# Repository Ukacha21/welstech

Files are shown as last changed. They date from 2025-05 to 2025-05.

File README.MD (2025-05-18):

# **WELSTECH**
#### *WEARABLE LIFE SAVER TECHNOLOGY*

#### Description:
**Welstech** is a wearable prototype in a type of wrist band that aims to deliver help to people with special needs. By constantly monitoring health conditions and their current status, the wearable prototype is able to tell wether the user is in situation that needs special care and immediate attention. Later on gives alerts the people nearby through a buzzer, with beeping intervals depending on how severe the condition is.

#### Components:
I will use `esp32-s3 mini/tiny` or `esp32-s3 zero` as the main microcontroller for this project. Here are all the components I'm gping to use in the project:
    
- **ESP32-S3 Zero**: Our main microcontroller.
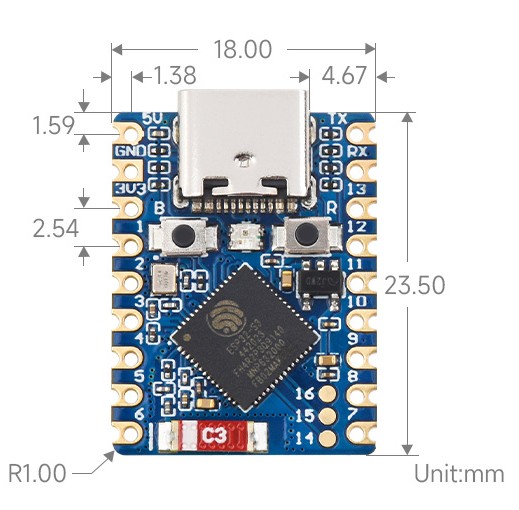
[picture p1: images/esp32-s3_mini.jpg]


- **Buzzer**: if we find a smaller one that can fit into the prototype.
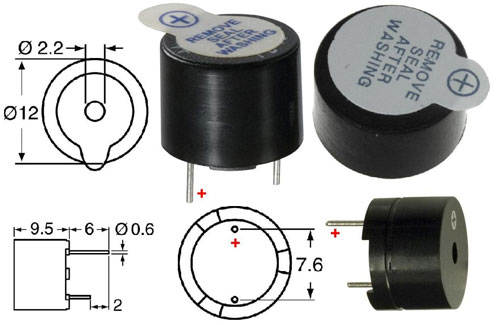
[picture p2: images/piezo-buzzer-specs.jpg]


- [`Removed`] **PushButton(Silent if possible)**: To be used as an action-button.
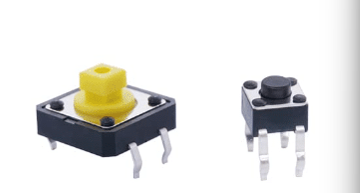
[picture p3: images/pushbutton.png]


- [`Removed/Still implementable`] **Switch**: To be used as feed or power interrupt between DCVin voltage supply and ground when necessary.
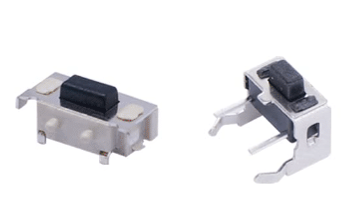
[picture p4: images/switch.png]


- [`Removed`] **Resistors**: a series of 10k resistors for pulldown and 330-OHM for LEDs(if necessary).
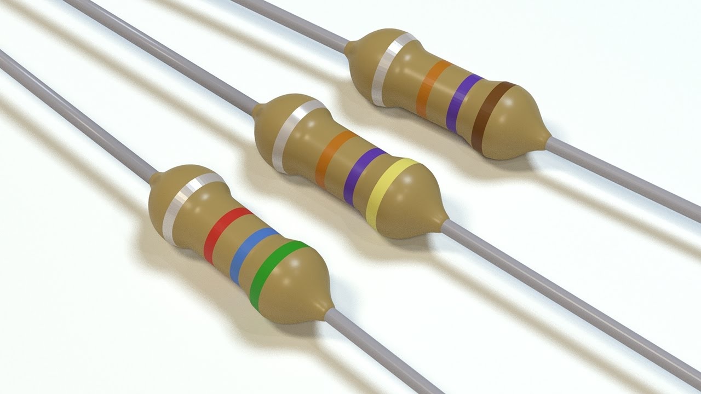
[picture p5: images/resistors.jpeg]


- [`Removed/Still implementable`]**Battery**: 3 pieces of 1.5 mini batteries connected in series,to output and average of 4.5V. Or 4 pieces and a silicon diode to drop voltage near 5.xV.
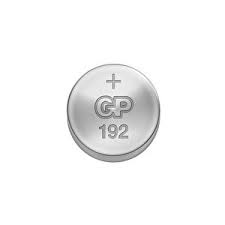
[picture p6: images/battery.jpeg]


- **Heart Pulse Monitor Sensor**: The sensor that will sense peak values and return data about the pulse of the user.
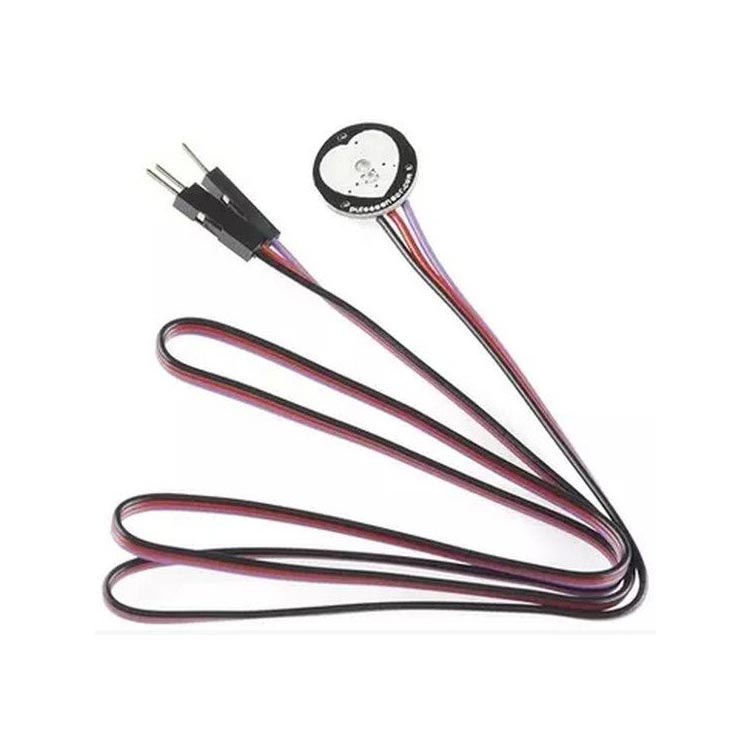
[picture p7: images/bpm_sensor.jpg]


- [`Removed`] **0.96" OLED Display**: To display data when necessary.
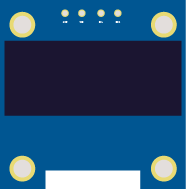
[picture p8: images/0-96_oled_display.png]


- **Jumper Wires**: To be used during Demo, before product release.
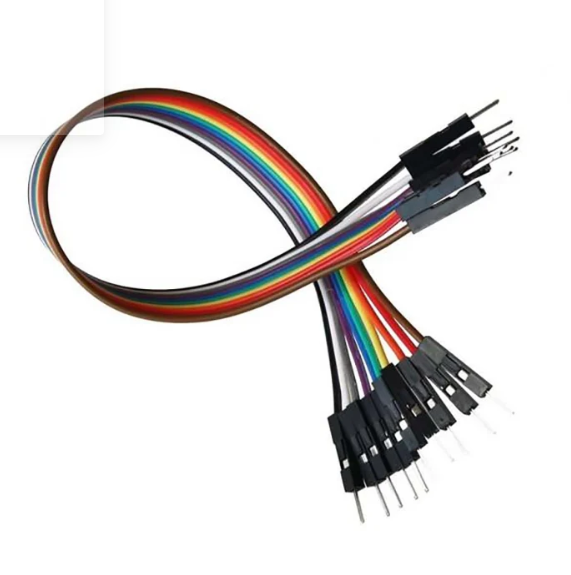
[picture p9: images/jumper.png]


- [`Removed`] **Perforated Board Soldering PLate**: The main circuit plane, to be soldered onto the base.
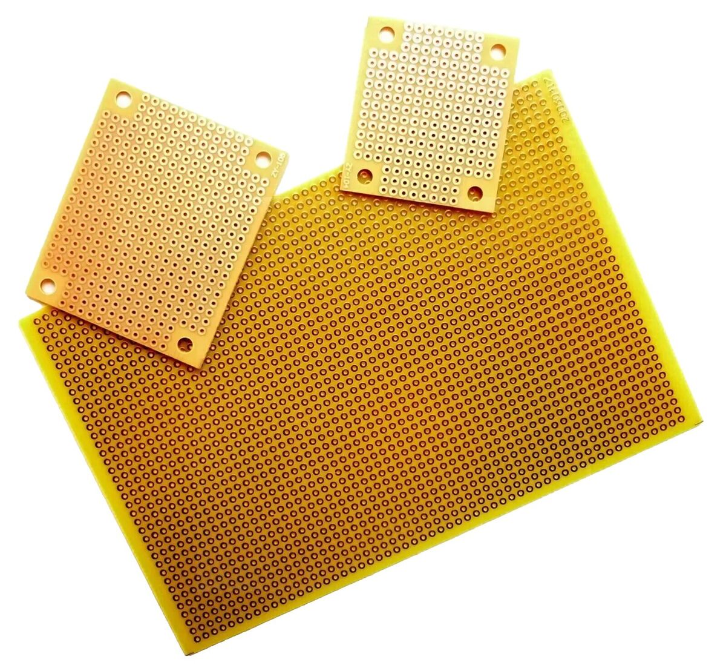
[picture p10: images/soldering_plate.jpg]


- **Thin Wires**: Thin circuit wires to be soldered onto the Welding plate and used ın other components.
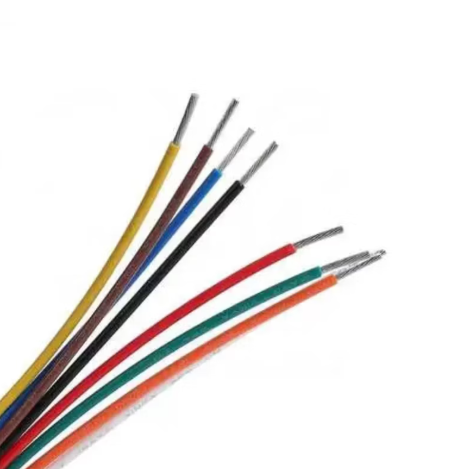
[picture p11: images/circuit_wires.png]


#### Algorithm:
As soon as the device is powered on with the code flashed and successfully uploaded, it shall start fetching the data from the heartrate pulse sensor, do the required normalization, calculate the average BPM and display it to the user in a human readable format. Here, after removıng the OLED Display, we are going to show the data through http protocol and continuous WiFi data streaming[locally].

If the BPM read is below a certain threshold--to be different for each user(eg. football player vs a teacher)--the buzzer will give a warning, short beeps-- or the mobile will notify the user and anybody else chosen among SOS contacts. In this mode, the action button will function as a silencer or mute button, to indicate that everything is okay. If the button is not pressed to mute the buzzer within a certain time, the buzzer play intervall will gradually increase, untill someone--rescue team or emergency service--presses it. The rescue team will be able to read from the display as well to facilitate their work in telling the user's(or patient's) current status and probably predict the reason of passing out.

#### Why **WELSTECH**?------start from here later on
Taking people with special needs into consideration and as a our main targeted audience, welstech aims to minimize the need of continuous human supervision, and decrease it to as much as possible. As previously said, if a button is not pressed within a certain amount of time, it does not necessarily mean that the user is unconcious, rather a starting point to tell the environment around it that urgent attention is needed.

#### [`OLD Schematic`] Schematics:

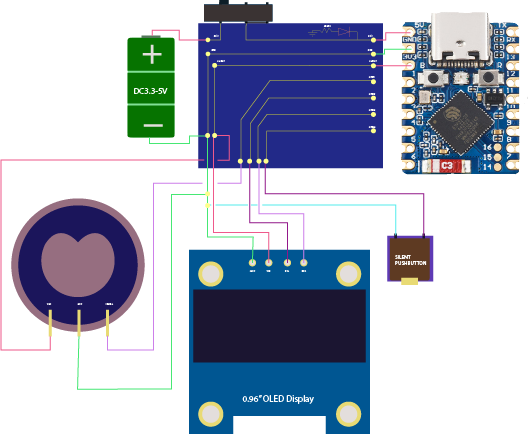
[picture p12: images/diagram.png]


----

#### [`NEW Schematic`] Schematics:

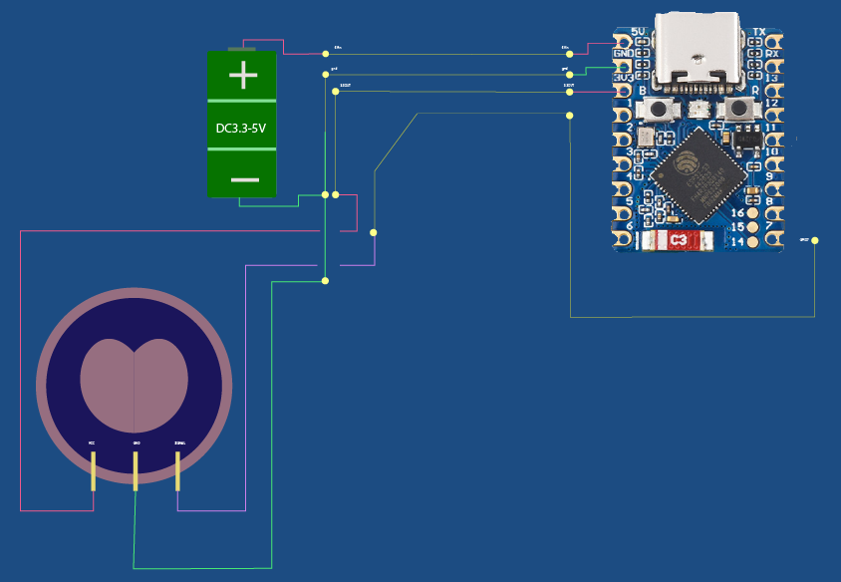
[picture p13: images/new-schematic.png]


#### What can be improved?

* find a smaller buzzer to use as environmental warning method.

* [`Done-with integrated BLE-WiFi`] use a bluetooth and/or wifi module to enable communication peripherals between the esp32 and a the phone.

* if we manage to find a smaller bluetooth or wifi modules, as tiny as possible we could no longer need esp32 and use microhips, such as pic16f84x, pic16f877x or stm32 chips. Thus minimizing significantly the size of the main base prototype.

## Mobile App:

Welstech Mobile is the name of the mobile app, currently almost finished, done with flutter and dart for elegancy and minimalism.

Mobile app is ready, just waiting to succedd connectiing to bluetooth with  the name specified on th code[**`ESP32_BT`**], to see if it works.

---

## Updates:
* `WiFi or Bluetooth`: 

**Wifi**: We started with Wifi.h, the plan was to use wifi for faster information and data transfer. The biggest drawback was oled's sensitivity ti heat, it could stop working as expected after a while, it was affected for being too close the esp32 main board.  And the challenge here it manage the esp32's heat dissipassion which did not turn out as easy as it looked.

**Bluetooth**: The alternative solution for this seemed to be switching to bluetooth. It's important to keep in mind that some esp board do not support `bluetooth classic` as it is in our case--ESP32S3-Zero, being Bluetooth Low Energy BLE. The most recommended BLE libraries are 

* NimBLE - Optimized for Wearables and compact devices -- third party lib.
* BLEServer - Built in llibrary that comes with espressif lib managger.

We tried NimBLE, we could upload the test code to the board successfuly, but it wouldn't broadcast, and thus, we could  find the board in the nearby BLE devices, after sca.

So we swiched to BLEServer, we uploaded the test code successfully for BLEServer to our esp board, it does appear in the scanned nearby devices list, but somehow we're failing to connect.  I tried with `Redmi 12 Pro`, `Redmi 7 Pro` and `Samsung tab S7 FE`. The Xiaomis appear to try to connect, even tho unsuccessful, it appears in the list of paired devices. Samsung on the other hand, seems to be the most too the point, telling us exacly that it failed to connect.

### Solution?

For now, the solution seems to be removing the display, and relying entirely on web based platforms to access the data, read and visualize.

Current plan is to completely redesign  the prototype and circuit element, remove the screen, buzzer had already been removed, still thinking about the action button. And keep the main board, sensor, and the prototype's cover, the case itself. 

Step 2: Switch back to wifi, use telegram bot for communication, and see if we can integrate the bot's retrieved information into our welstech mobile flutter app. Remodel the prptptype's case to put some ventilation pathways to relief the heat amd help with heat dissipation.

## Updates:
We are currently using ESP's wifi on access point mode, initialized hotspot from the esp board, coonnected to it from the browser, and typically we should be able to access any stremmed data from the browser using "192.168.4.1". And it worked.

#### Sample test on http protocol:

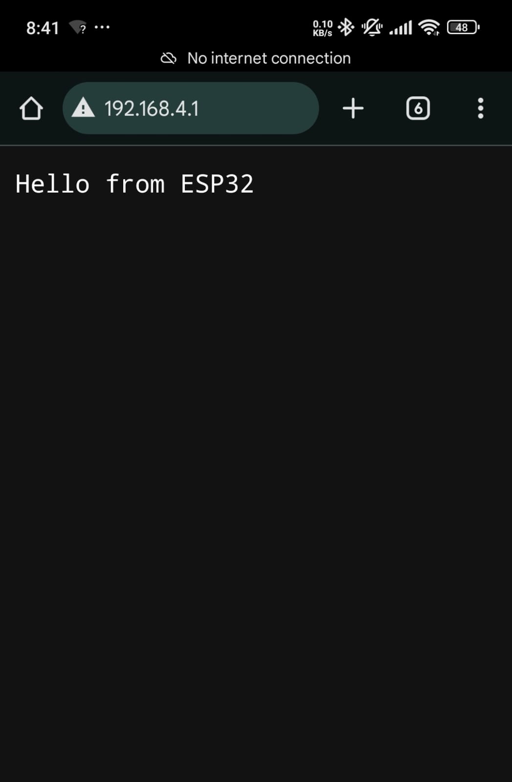
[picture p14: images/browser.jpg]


Now tring to access it using socket from the flutter side, raised multiple errors. Soo instead or raw socket and/or tcp we just used http client and updated the dependecies in our pubspec.yaml.

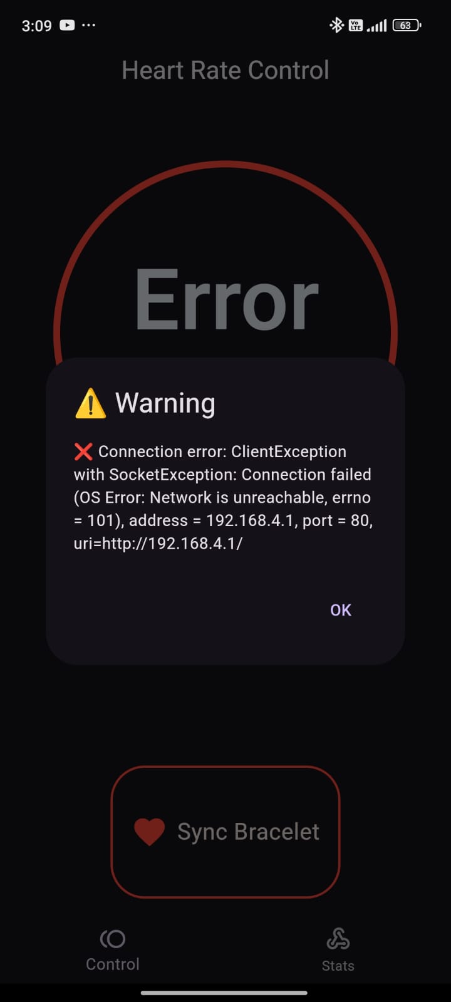
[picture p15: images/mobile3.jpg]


After some  reseaches i came to know that emulators do not allow raw http data for security reasons, so after each minor change, i would have to rebuild the apk file and try on a real mobile device. Now lets do that, best of luck.

#### Sample test on http protocol:

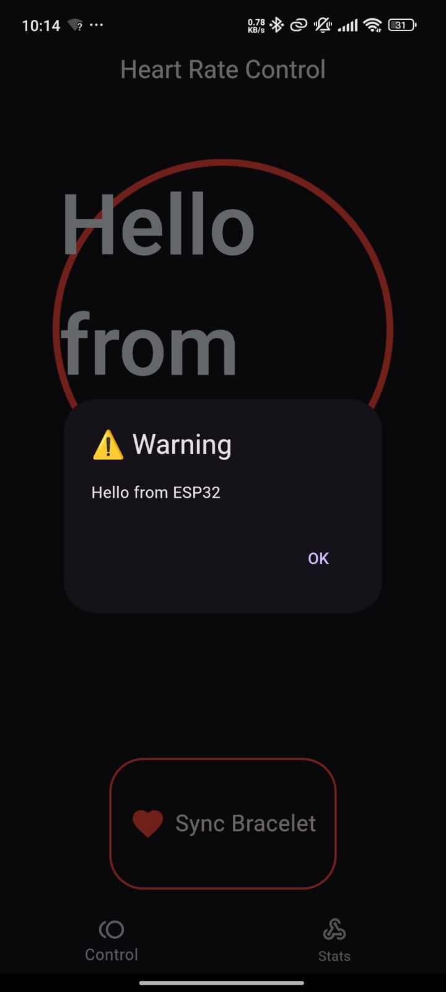
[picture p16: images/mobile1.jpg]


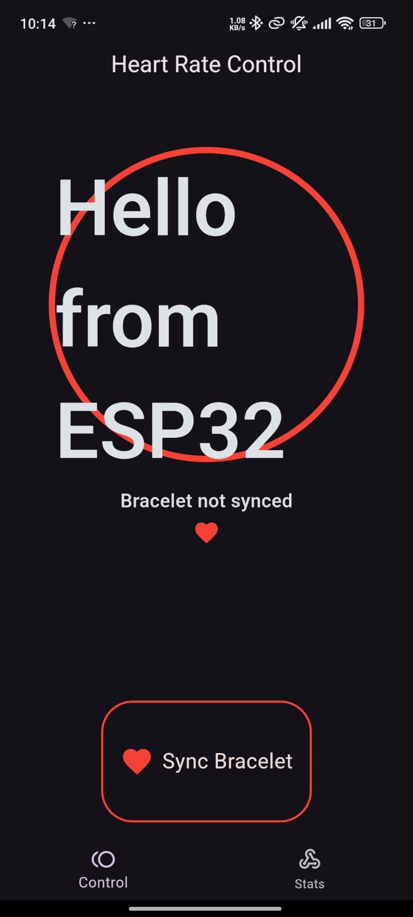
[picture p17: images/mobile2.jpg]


And another thing, if we managed to get the data from the browser, we can now be sure to remove the screen, and now we can 3D print the smaller prototype with small holes to be used as vents.

Now we successfully got the data on the mobile app, for now we just tried to show the analog value that the sensor returns as raw data, using readAnalog(). We did not calculate any BPM up until here:

#### Data on flutter  app:

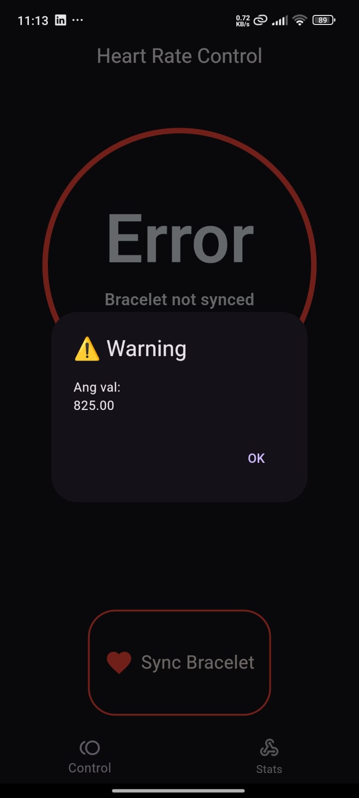
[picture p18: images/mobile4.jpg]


## Updates: 

Project is successfull, now we can print the 3D prototype and improve the mobile side, to read the values every 10 seconds and return the estimate bpm.

One more thing, we still havent gotten the optimum threshold, this can only be done either by changing small values every time, or watching the peak changes closely from the mobile phone, http in the browser cannot update itself every second, that is something to be imlpemented in the mobile. to make requestas every half a second or 200 ms, to detect the optimum threshhold, and calculate bpm accordingly.

## Updates: 

A mistake made by me, caused the deliver of the prototype to take longer than expected. 

Printed the 3D base, but came out larger than thought of. And the reason for that is, I had measured the diameter as 43mm, but when modeling the surpafecs on solidworks, I mistakenly put 43 as the radius, and it turned out larger than expected.

#### Faulty Prototype:

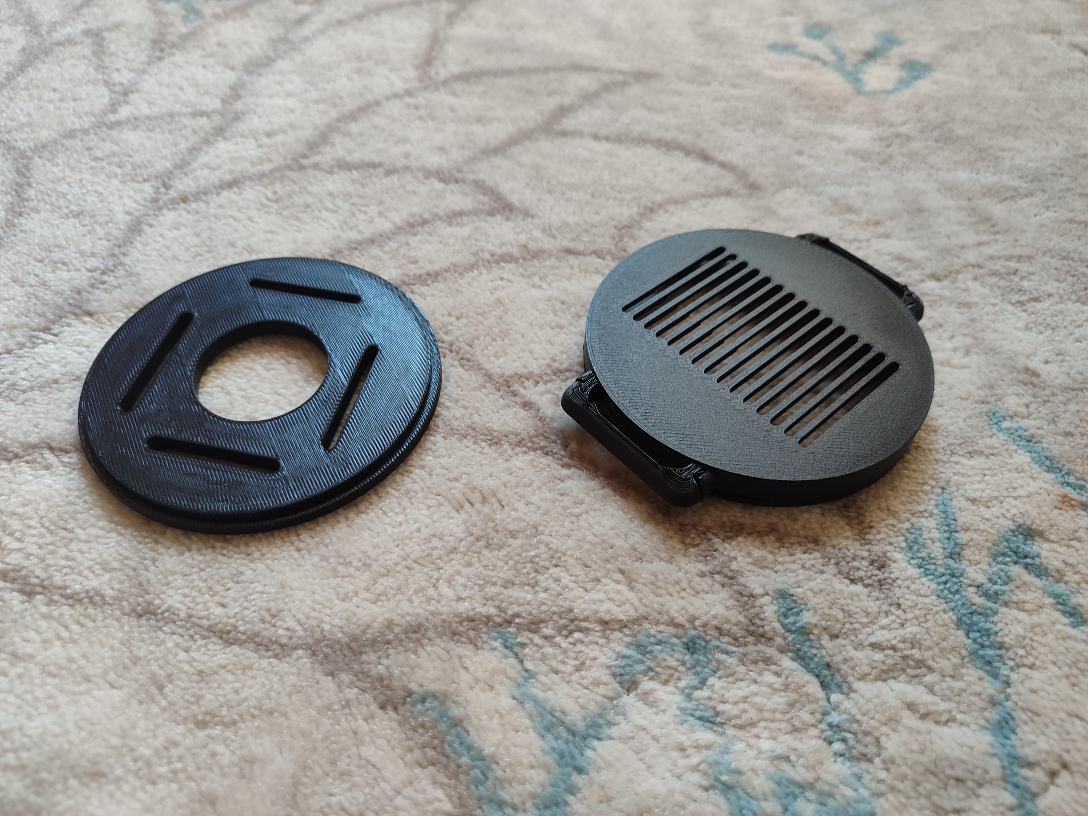
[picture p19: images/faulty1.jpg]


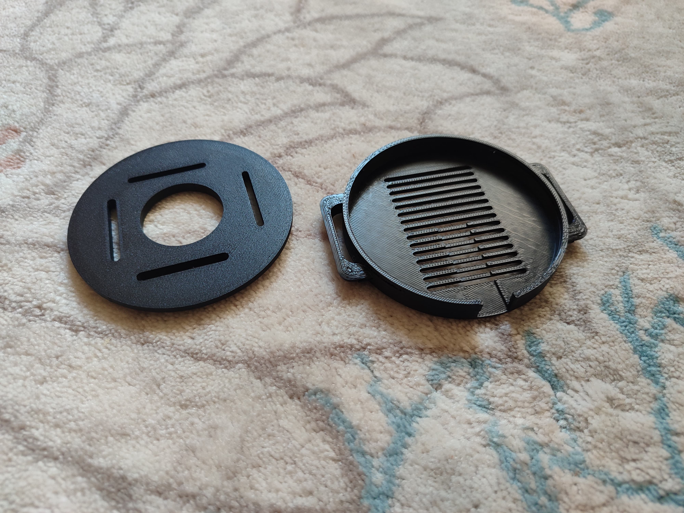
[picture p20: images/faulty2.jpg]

#### Comparing the sizes to a real watch:

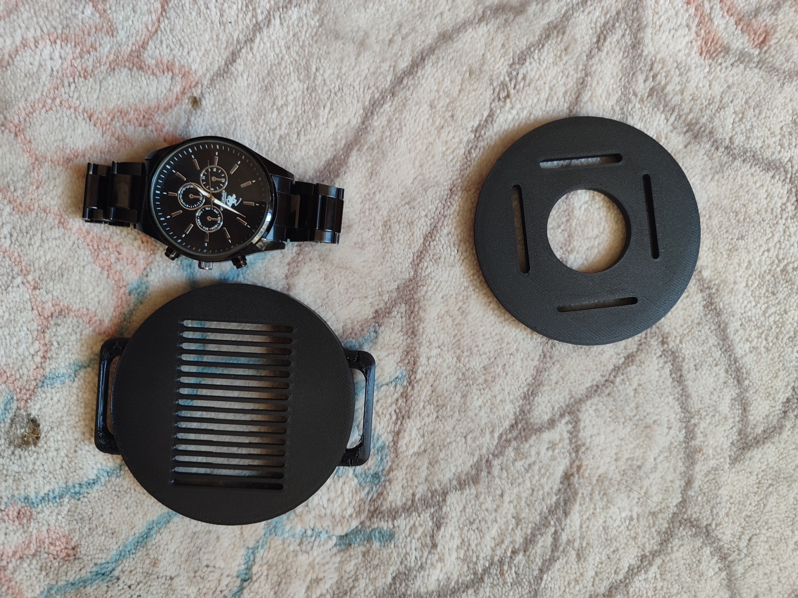
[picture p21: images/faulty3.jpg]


While redesiging on Solidworks, we're basicaly just going to set the new sizes as half of the previous ones. e.g: 'instead of 43, use 43/2'. Taking its rescpective tolerances into consideration of coursse.

## Updates: 

After printing our latest protype and placing the microcontroller and sensor inside, it worked just fine. 

The  optimum threshold is 852, and the Average output BPM rate was a value in the  interval of 96-100.

## Results: 

Current prototype and finished design:

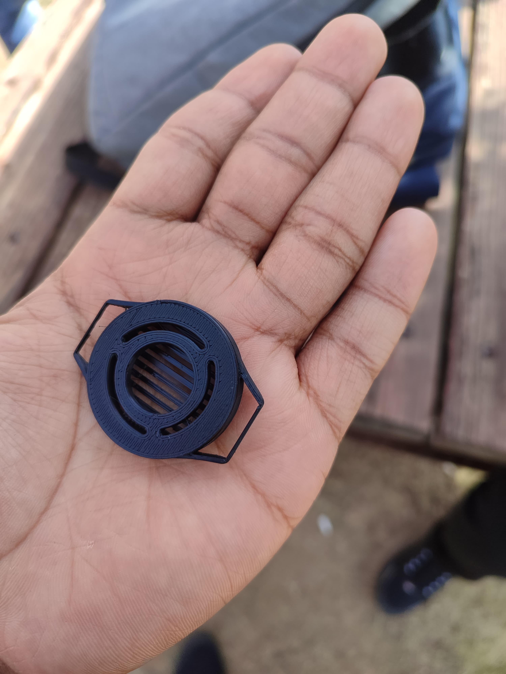
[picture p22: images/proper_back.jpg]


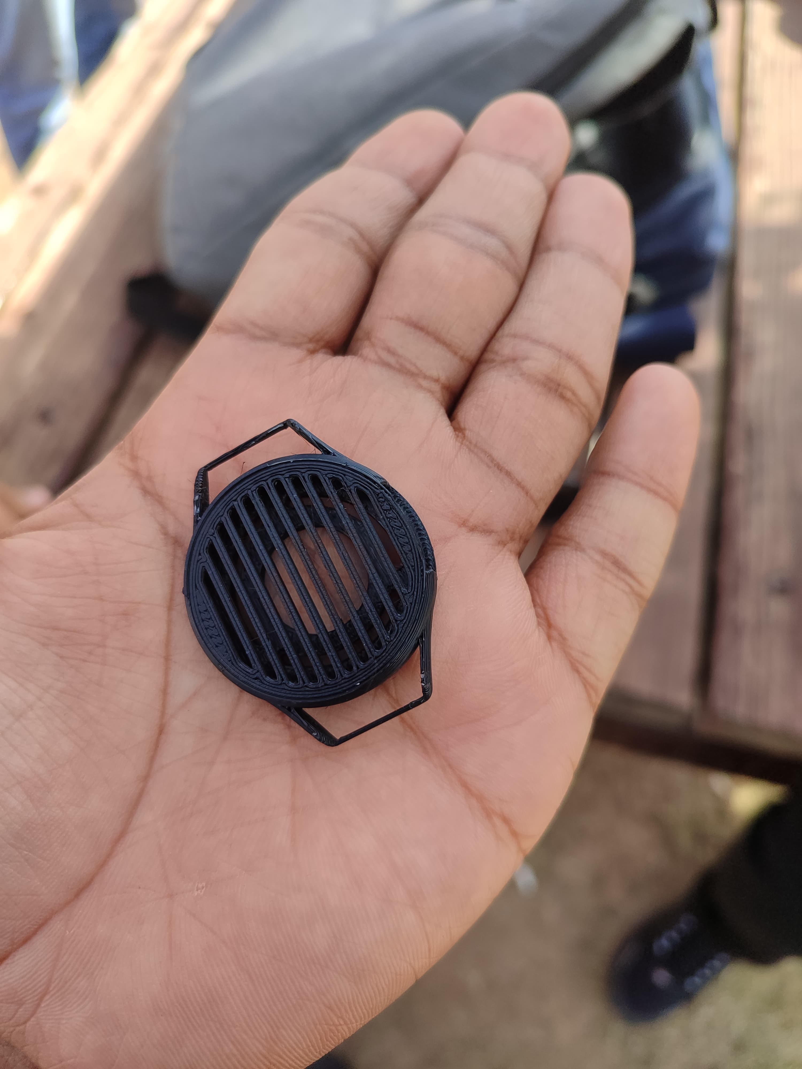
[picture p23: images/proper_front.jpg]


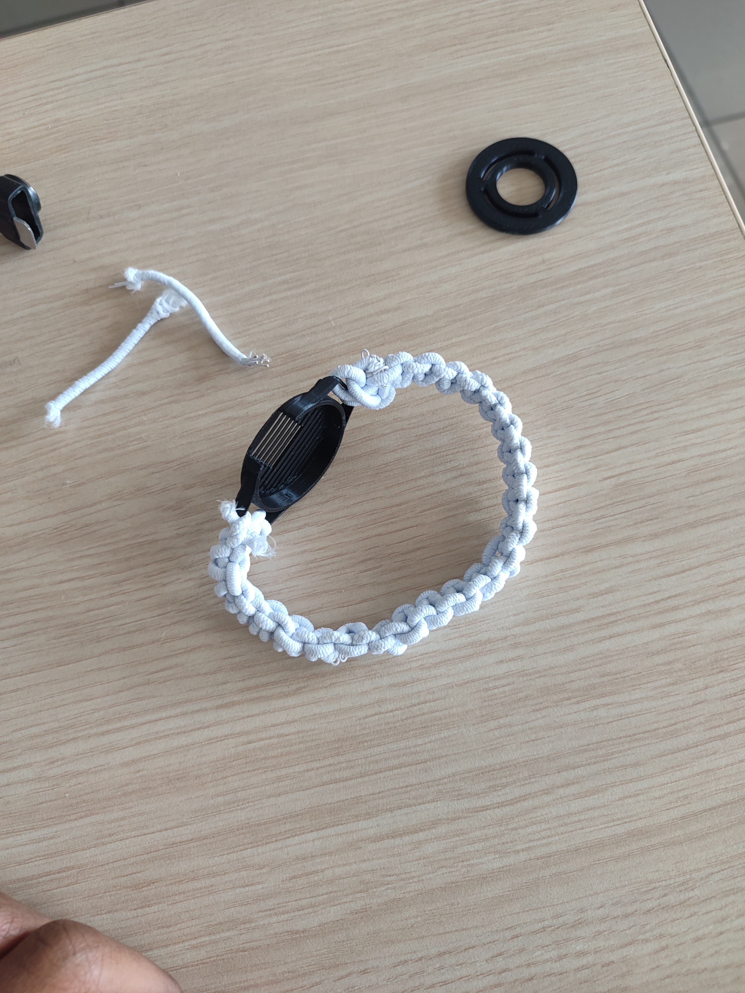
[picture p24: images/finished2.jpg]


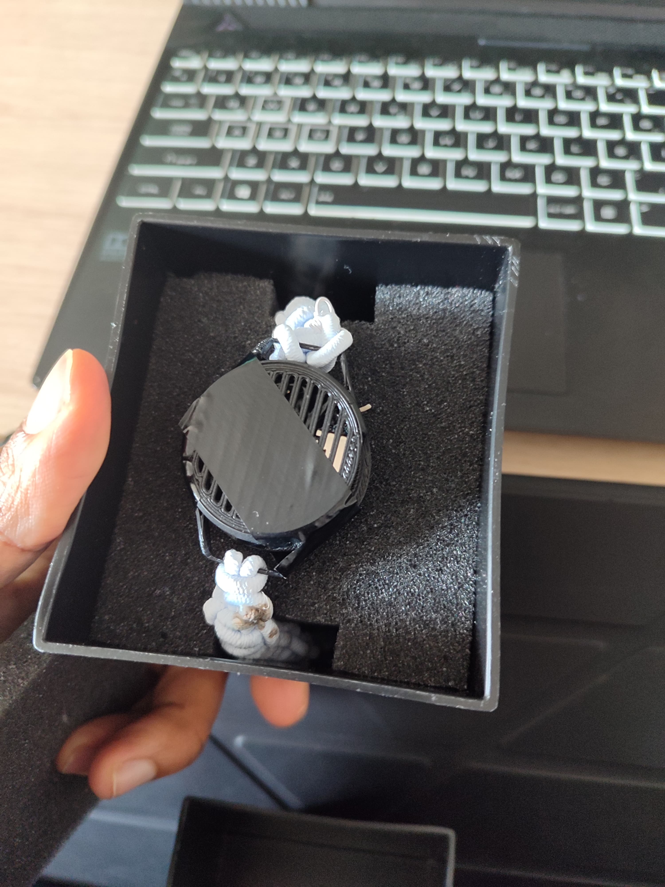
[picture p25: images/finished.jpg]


---------

The fisrt thing shown when app in not in sync with bracelet, the background borderline colors turn red. 

After sync it turns blue

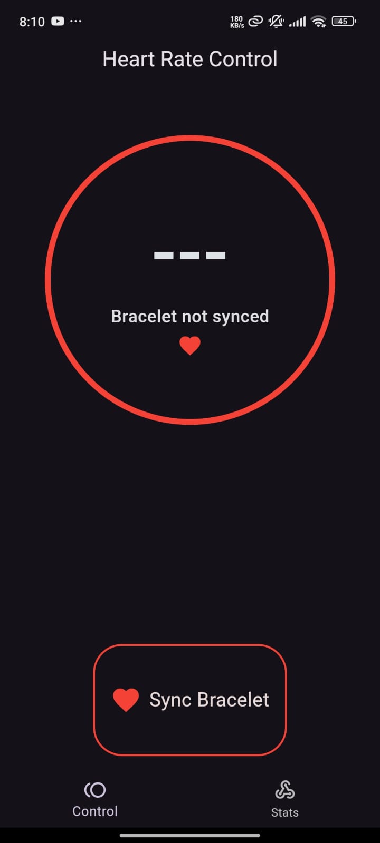
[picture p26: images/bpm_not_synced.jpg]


And here the average BPM results:

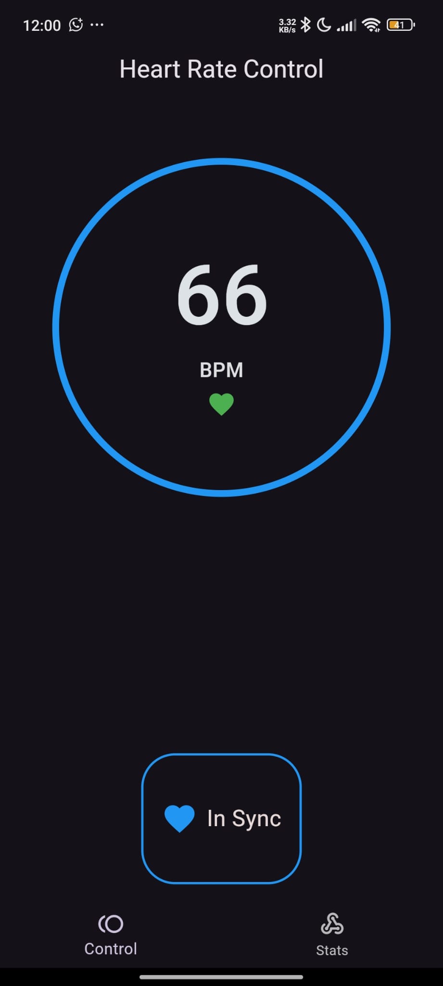
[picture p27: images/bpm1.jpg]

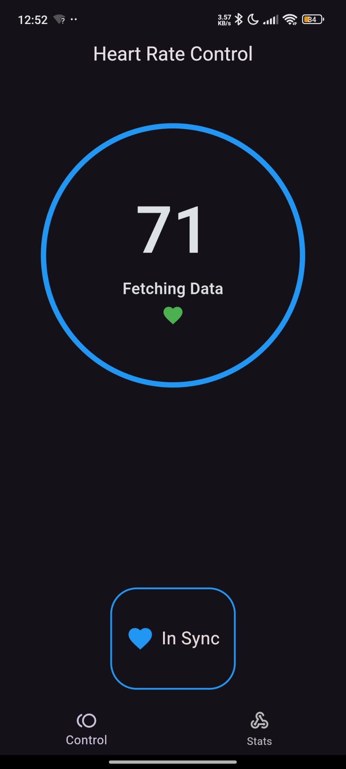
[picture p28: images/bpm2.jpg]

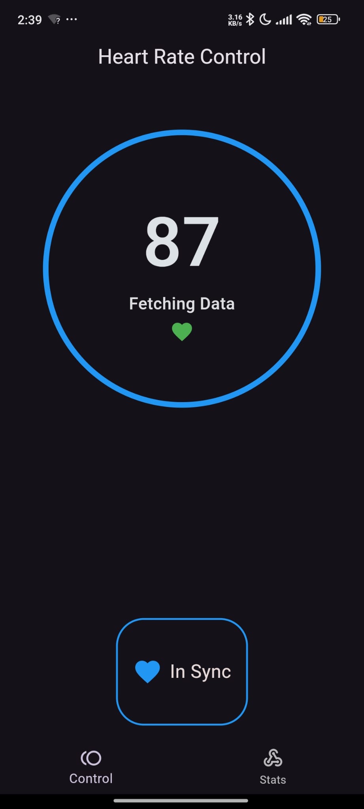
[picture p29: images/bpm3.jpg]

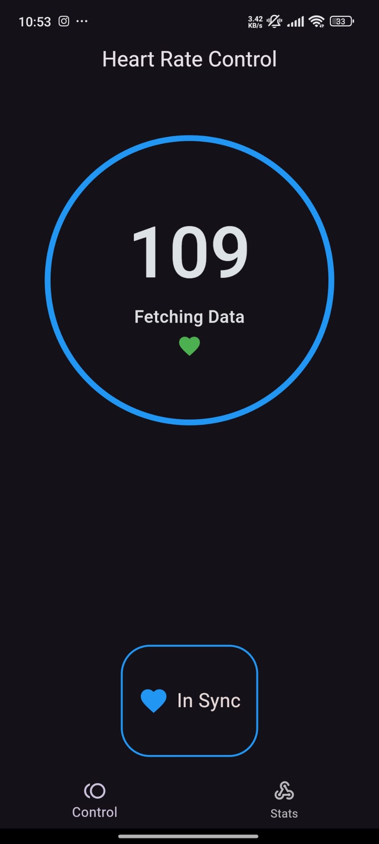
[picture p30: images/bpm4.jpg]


Detailed Video on Youtube:

[welstech video](https://youtu.be/DE1oGRj5kBM?si=-mU4gTcb0TAKlGFt)

## What can be added or improved?

 * GPS Location
 * Instead of WiFi, use BLE--Bluetooth Low Energy--to significantly prevent board overheat
 * Send SMS, Telegram or Whatsapp text to contact--GSM may be needed
 * Add a physical action button
 * If possible use a smaller batttery(rechargeable and batter charging and feed circuit integrated)
 
 * ...

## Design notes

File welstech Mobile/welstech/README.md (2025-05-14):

# welstech

A new Flutter project.

## Getting Started

This project is a starting point for a Flutter application.

A few resources to get you started if this is your first Flutter project:

- [Lab: Write your first Flutter app](https://docs.flutter.dev/get-started/codelab)
- [Cookbook: Useful Flutter samples](https://docs.flutter.dev/cookbook)

For help getting started with Flutter development, view the
[online documentation](https://docs.flutter.dev/), which offers tutorials,
samples, guidance on mobile development, and a full API reference.

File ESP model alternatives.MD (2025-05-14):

For a smartwatch project, you need a **compact ESP32 module** that supports **low power consumption**, **small form factor**, and **easy reprogramming**. Here are some great options:

### **Best ESP32 Models for Smartwatch Projects**
#### 1️⃣ **ESP32-S3 Mini**
   - ✅ **Ultra-small** (18mm × 25mm)
   - ✅ **Low power mode** (deep sleep support)
   - ✅ **USB Type-C for programming** (no need for an FTDI adapter)
   - ✅ **Better power efficiency**
   - ⚡ **More GPIOs available** compared to ESP32-C3

#### 2️⃣ **ESP32-C3 Mini**
   - ✅ **RISC-V processor** (efficient and small)
   - ✅ **USB direct flashing** (easier than ESP32-CAM)
   - ✅ **Lower power than standard ESP32**
   - ✅ **Built-in BLE + WiFi**

#### 3️⃣ **ESP32-PICO-D4**
   - ✅ **Extremely small (7×7mm)**
   - ✅ **Low power and energy-efficient**
   - ✅ **Good for battery-powered wearables**
   - ❌ Harder to solder since it's an SMT module

#### 4️⃣ **ESP32-S3-WROOM-1**
   - ✅ **More powerful (Dual-core)**
   - ✅ **Native USB support**
   - ✅ **Good balance of size & power**
   - ❌ Slightly bigger than other options

---

### **Best Choice?**
If **size** and **ease of programming** are top priorities:
- **ESP32-S3 Mini** or **ESP32-C3 Mini** (Best for smartwatches)
- **ESP32-PICO-D4** if you need **the smallest size**
- **ESP32-S3-WROOM-1** if you need **more power**

Would you like suggestions for a **display**, **battery**, or **sensor** for your smartwatch? ⌚🚀

-----------

For a smartwatch with **WiFi support**, here are the best ESP32 options:  

### **1️⃣ ESP32-S3 Mini** (Best for compact wearables)  
   - ✅ **WiFi + Bluetooth 5.0**  
   - ✅ **USB Type-C for easy programming**  
   - ✅ **Small size (18mm × 25mm)**  
   - ⚡ **Low power mode available**  

### **2️⃣ ESP32-C3 Mini** (Efficient & compact)  
   - ✅ **WiFi 4 + BLE 5.0**  
   - ✅ **Direct USB flashing**  
   - ✅ **Lower power consumption**  

### **3️⃣ ESP32-PICO-D4** (Ultra-small option)  
   - ✅ **WiFi + BLE**  
   - ✅ **Extremely compact (7×7mm)**  
   - ❌ Harder to solder (SMT package)  

### **4️⃣ ESP32-S3-WROOM-1** (Powerful & versatile)  
   - ✅ **Dual-core processor**  
   - ✅ **WiFi + BLE**  
   - ✅ **Native USB support for programming**  
   - ❌ Slightly larger than Mini versions  

---

### **Best Choice?**  
🔹 **For ultra-compact size** → ESP32-PICO-D4  
🔹 **For easy programming & USB support** → ESP32-S3 Mini / ESP32-C3 Mini  
🔹 **For more processing power** → ESP32-S3-WROOM-1  

Would you like display, battery, or sensor recommendations? ⌚🚀

---------

Yes! All the ESP32 modules I listed have **WiFi integrated**.  

Here’s a confirmation for each:  

### **✅ ESP32-S3 Mini**  
✔ **Built-in WiFi 4 (802.11 b/g/n)**  
✔ No external WiFi module needed  

### **✅ ESP32-C3 Mini**  
✔ **Built-in WiFi 4 (802.11 b/g/n)**  
✔ No need for an external WiFi chip  

### **✅ ESP32-PICO-D4**  
✔ **Integrated WiFi 4 (802.11 b/g/n)**  
✔ Super small but still has onboard WiFi  

### **✅ ESP32-S3-WROOM-1**  
✔ **WiFi 4 (802.11 b/g/n) onboard**  
✔ No external module required  

So, you won’t need **any external WiFi module**—just an antenna if needed for better signal strength. 🚀  

Would you like help choosing a **display** or **battery** for your smartwatch? ⌚🔥

---------

# Dimensions:

Here are the **dimensions** of the ESP32 modules I listed:  

### **1️⃣ ESP32-S3 Mini**  
📏 **18mm × 25mm × 3mm**  

### **2️⃣ ESP32-C3 Mini**  
📏 **13mm × 19mm × 3mm** (smallest with WiFi & USB)  

### **3️⃣ ESP32-PICO-D4**  
📏 **7mm × 7mm × 1mm** (ultra-compact, requires custom PCB)  

### **4️⃣ ESP32-S3-WROOM-1**  
📏 **18mm × 25.5mm × 3mm**  

---

### **Best for a Smartwatch?**  
- **Ultra-compact?** → **ESP32-PICO-D4** (smallest, but harder to solder)  
- **Small + USB flashing?** → **ESP32-C3 Mini**  
- **Balanced size & power?** → **ESP32-S3 Mini**  
- **More performance?** → **ESP32-S3-WROOM-1**  

Let me know if you need **screen or battery suggestions**! 🚀⌚

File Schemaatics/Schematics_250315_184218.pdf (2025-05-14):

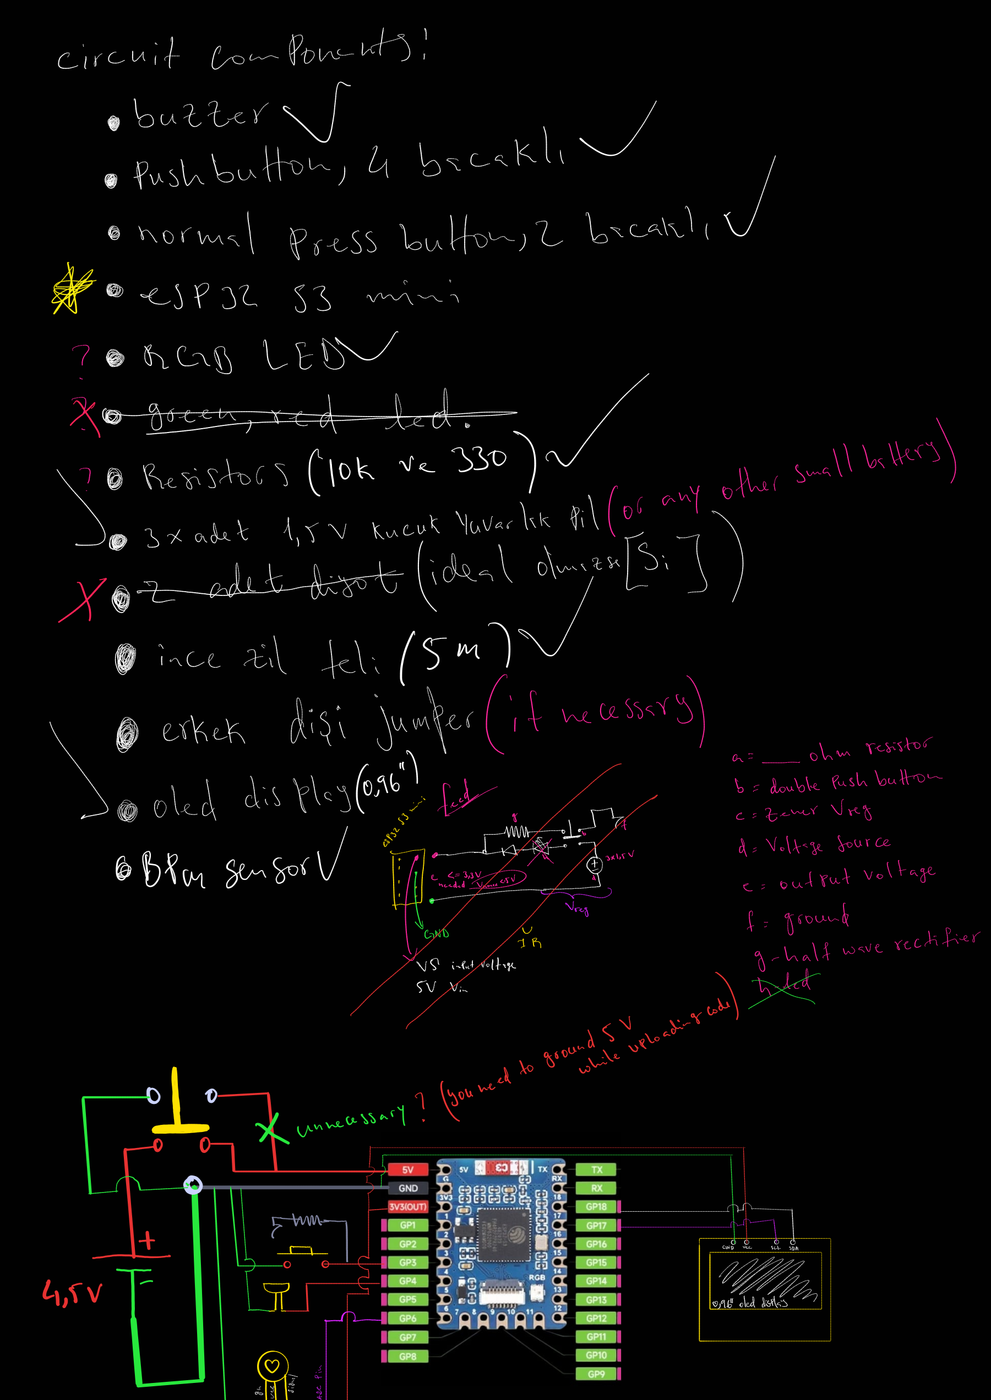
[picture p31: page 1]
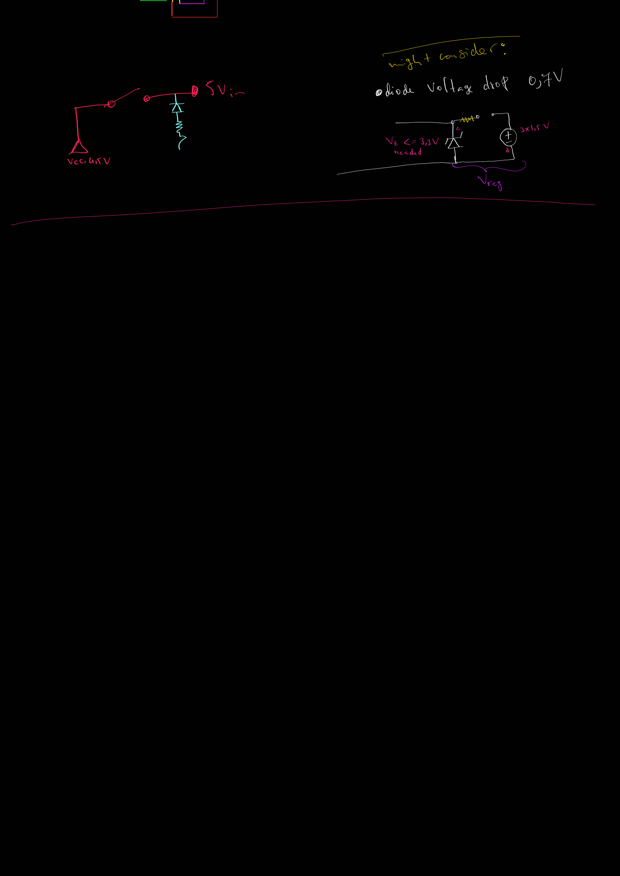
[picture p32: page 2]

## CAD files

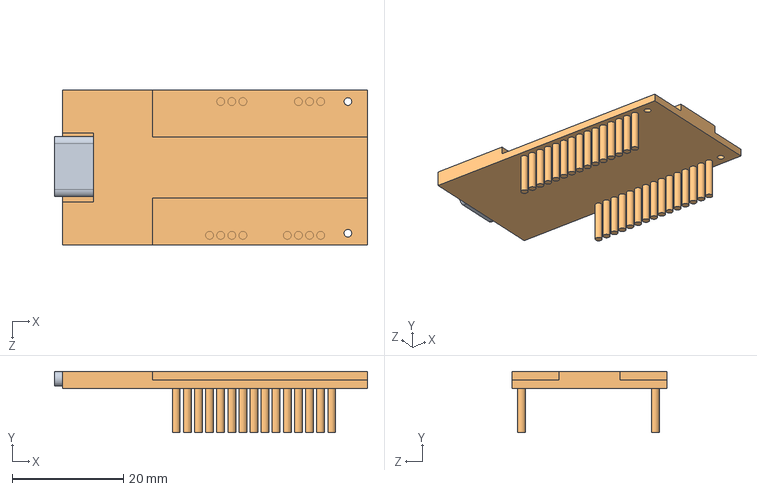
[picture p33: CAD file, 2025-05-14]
CAD/demo_big esp/esp assembly.SLDASM
56.3 x 11.0 x 28.0 mm
esp sim
usb c female port

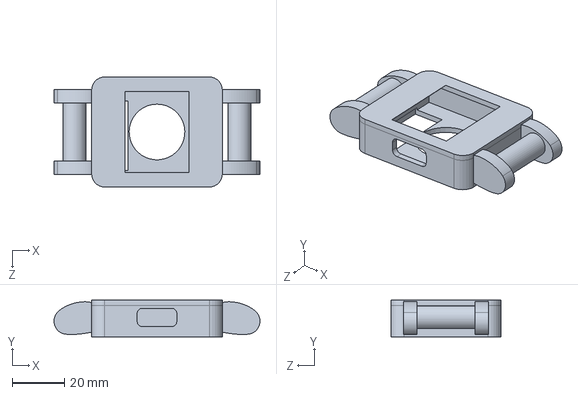
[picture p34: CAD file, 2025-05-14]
CAD/s3 casing/Demo/main base.SLDPRT
78.8 x 14.0 x 42.1 mm

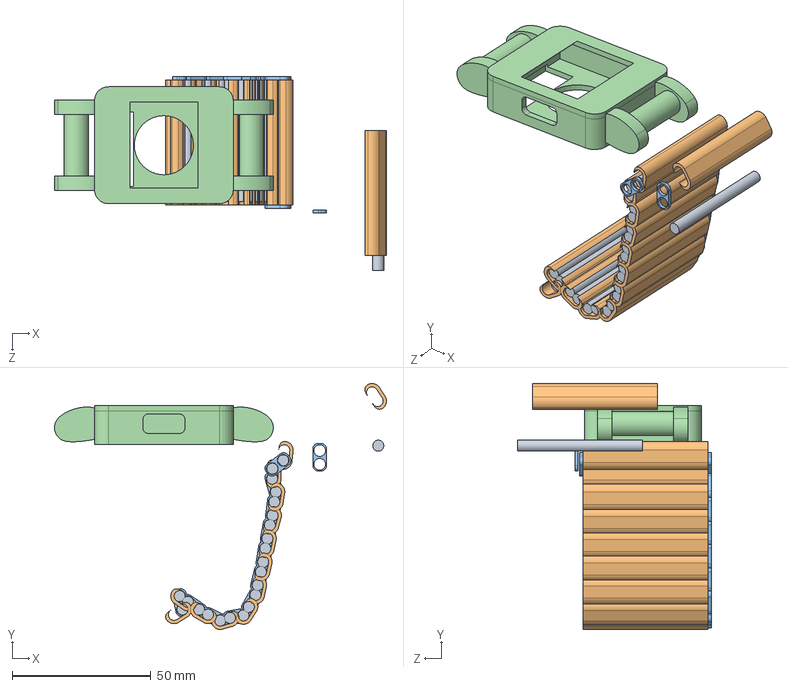
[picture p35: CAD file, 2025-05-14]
CAD/demo_big esp/prototype.SLDASM
119.5 x 88.6 x 69.7 mm
Main Base
stick spacers x 13
sticks connector x 13
cordon singlular sticks x 23

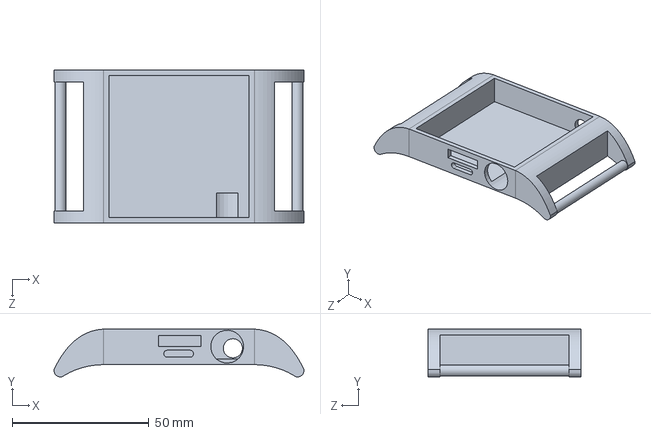
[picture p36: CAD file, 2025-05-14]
CAD/demo_big esp/Main Base.SLDPRT
91.2 x 17.5 x 56.0 mm

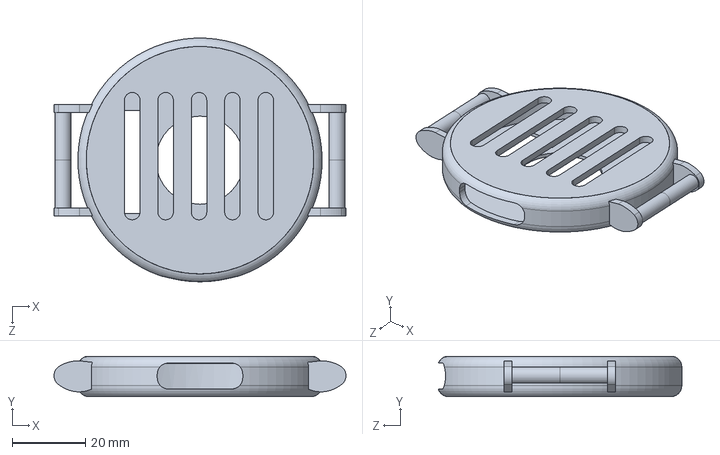
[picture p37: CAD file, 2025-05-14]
CAD/s3 casing/Demo/base without lcd.SLDPRT
79.6 x 11.0 x 66.4 mm

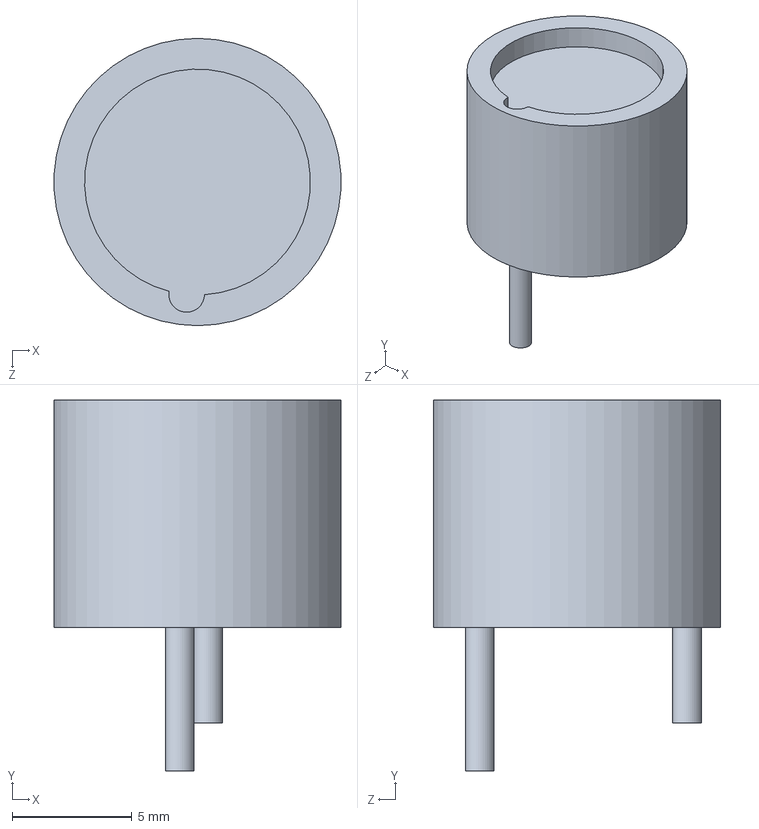
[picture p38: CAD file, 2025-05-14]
CAD/demo_big esp/buzzer.SLDPRT
12.0 x 15.5 x 12.0 mm

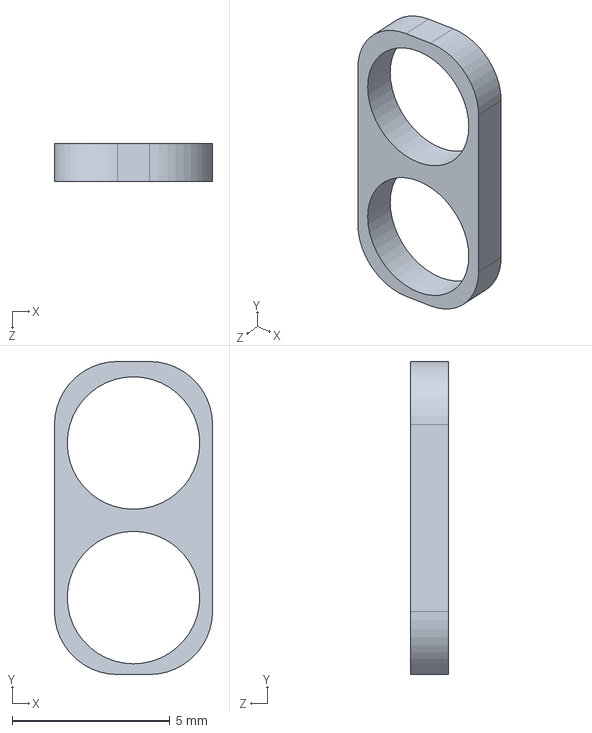
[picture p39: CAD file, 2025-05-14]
CAD/demo_big esp/stick spacers.SLDPRT
5.01 x 9.93 x 1.20 mm

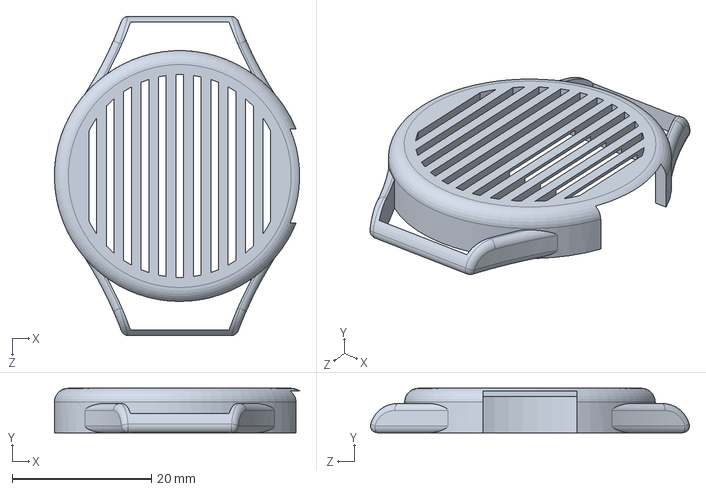
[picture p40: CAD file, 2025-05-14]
CAD/s3 casing/top.SLDPRT
35.2 x 6.40 x 45.8 mm

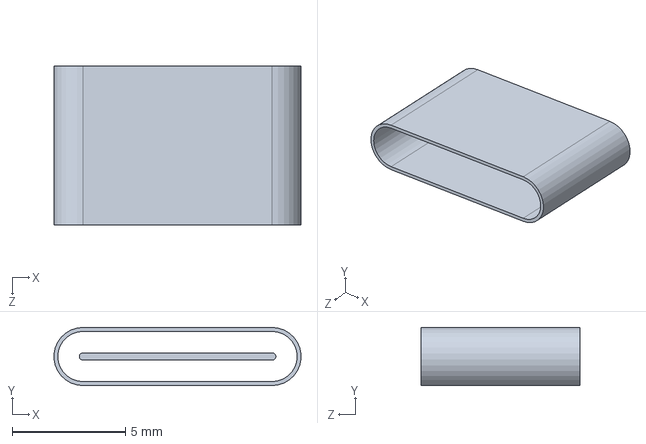
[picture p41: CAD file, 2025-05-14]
CAD/demo_big esp/usb c female port.SLDPRT
10.9 x 2.56 x 7.00 mm

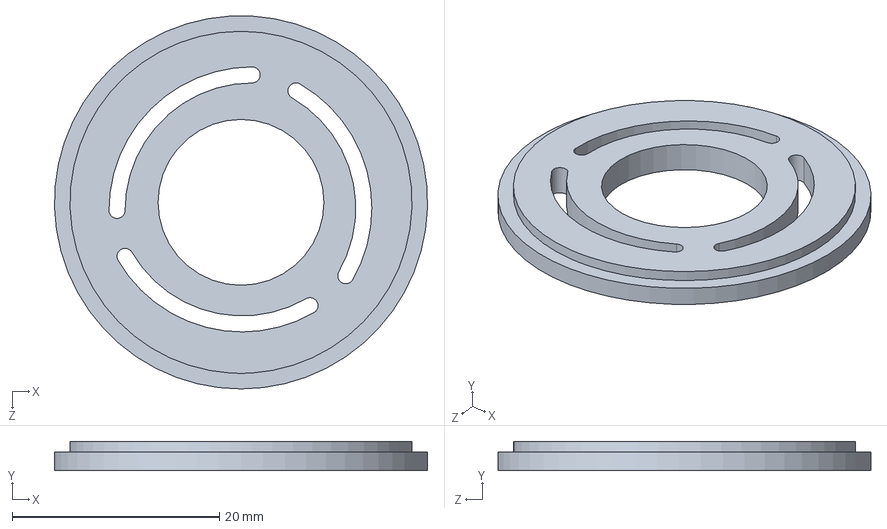
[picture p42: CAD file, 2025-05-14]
CAD/s3 casing/bottom.SLDPRT
36.0 x 2.80 x 36.0 mm

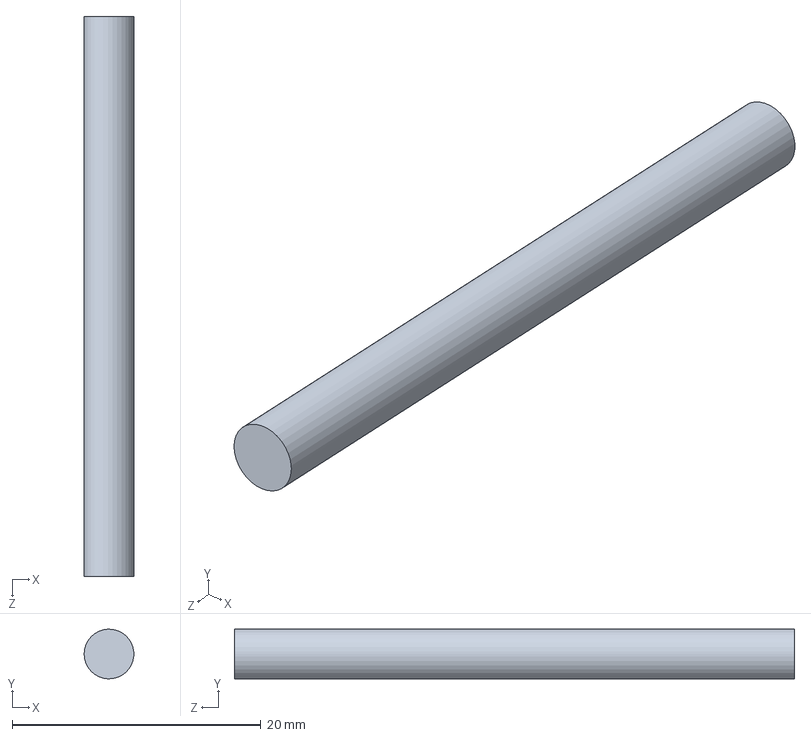
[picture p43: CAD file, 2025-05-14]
CAD/demo_big esp/cordon singlular sticks.SLDPRT
4.00 x 4.00 x 45.0 mm

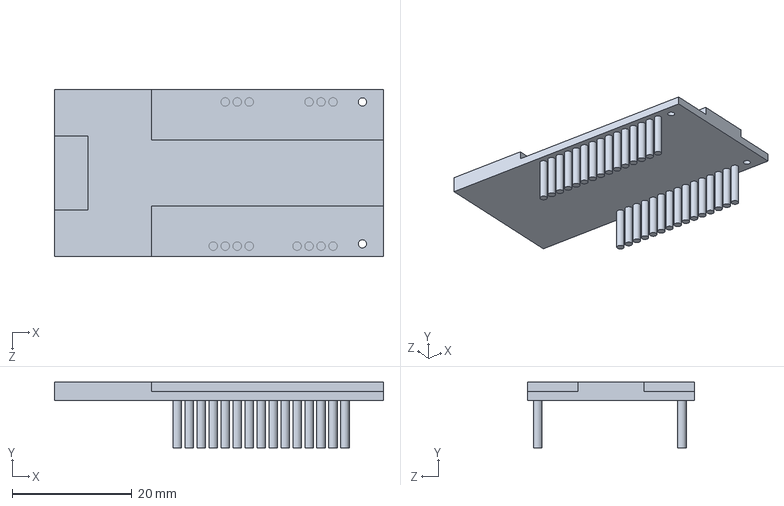
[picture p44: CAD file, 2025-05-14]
CAD/demo_big esp/esp sim.SLDPRT
54.9 x 11.0 x 28.0 mm

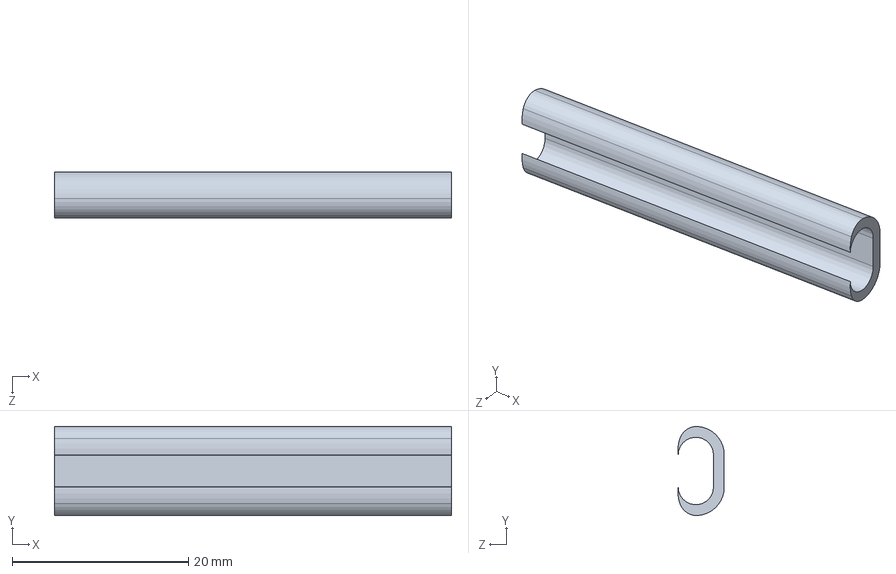
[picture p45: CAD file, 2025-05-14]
CAD/demo_big esp/sticks connector.SLDPRT
45.0 x 10.1 x 5.23 mm

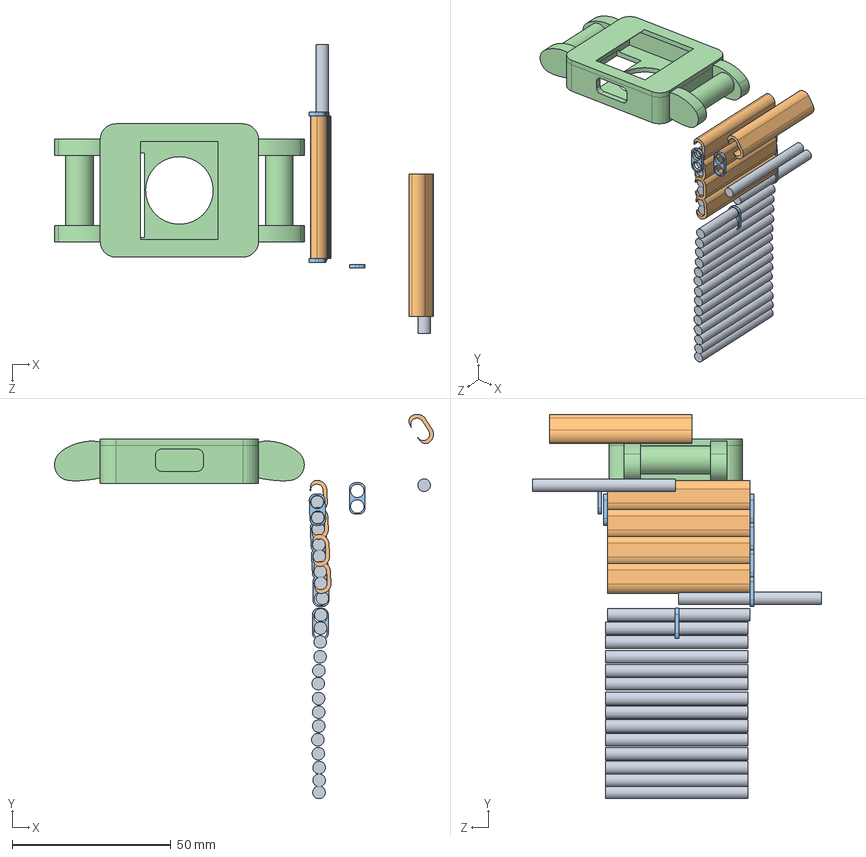
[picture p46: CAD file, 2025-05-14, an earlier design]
CAD/demo_big esp/prototype - Copy.SLDASM
119.5 x 121.2 x 91.0 mm
Main Base
stick spacers x 7
sticks connector x 5
cordon singlular sticks x 23

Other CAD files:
CAD/s3 casing/top - Copy (2).SLDPRT
CAD/s3 casing/top - Copy - Copy.SLDPRT
CAD/s3 casing/Demo/base without lcd - Copy.SLDPRT
CAD/s3 casing/top - Copy.SLDPRT
CAD/s3 casing/bottom.STL
CAD/s3 casing/top.STL

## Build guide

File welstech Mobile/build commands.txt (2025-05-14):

flutter build apk --build-name=1.0 --build-number=1 
flutter build windows --release

#build options
--release / --debug

#split for different versions
--split-per-abi

//currently used
flutter build apk --release

first do

flutter clean
flutter pub get

//and then build to whatever target platform it is
flutter build apk or windows --release

//and sometimes run with verbosem if emulator fails

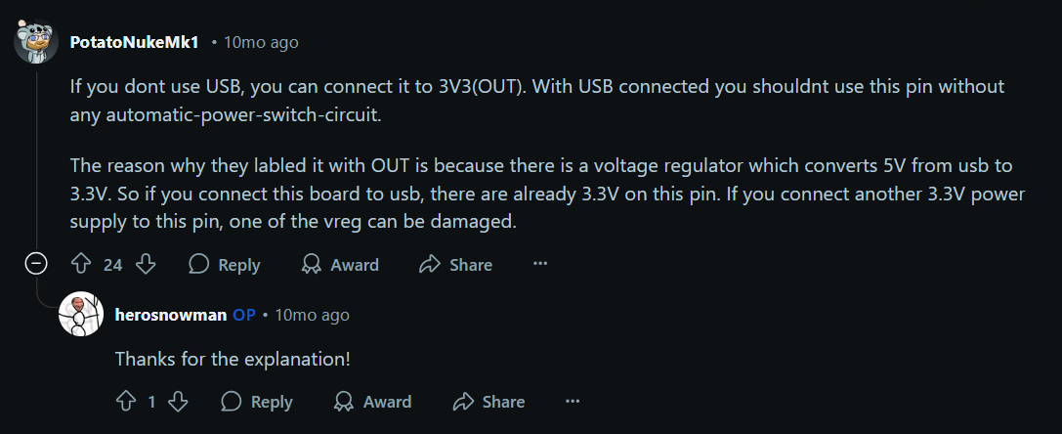
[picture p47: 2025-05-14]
Schemaatics/how to power with 3.3 Volts.png

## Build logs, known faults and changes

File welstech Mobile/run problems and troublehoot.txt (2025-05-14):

use the following to run on edge effectivelty

	flutter run -d edge --verbose 
or 
	flutter run -d chrome --verbose 

depending on the browser

//clear everything, browser cache etc, before re-run, if failing:

flutter clean
flutter pub get
flutter run -d edge

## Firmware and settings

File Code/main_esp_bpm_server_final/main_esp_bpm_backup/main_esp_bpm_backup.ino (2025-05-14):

#include <Wire.h>
// #include
#include <Adafruit_GFX.h>
#include <Adafruit_SSD1306.h>

// #include <SPI.h>


// Define the OLED display object
#define SCREEN_WIDTH 128
#define SCREEN_HEIGHT 64
#define OLED_RESET -1

/*


*/

// Define custom SDA and SCL pins
#define SDA_PIN 2
#define SCL_PIN 4

// Create an instance of the display
Adafruit_SSD1306 display(SCREEN_WIDTH, SCREEN_HEIGHT, &Wire, OLED_RESET);

// I2C address of the display, usually 0x3C or 0x3D
// #define SSD1306_I2C_ADDRESS 0x3C //0x3C or 0x3D
// Define the I2C address for the SSD1306
#define OLED_I2C_ADDRESS 0x3C  

//  0x3C // MOST COMMON
//  0x3D
//  0x3A
//  0x3E
//  0x76

#define SENSOR_SIGNAL_PIN_ADC 7  // GPIO1 for the heart rate sensor signal
#define ACTION_BUTTON_PIN 12 //gpio12

// about sensor----------------

//for getpulse2

//----------
#define MIN_BPM 30     // Set a minimum heart rate threshold for valid data
#define MAX_BPM 200 
#define NUM_SAMPLES 5

//last try variables ---------

//-----------
int threshold = 1995;   //1980 Adjust this based on your readings
bool peakDetected = false;
unsigned long lastPeakTime = 0;
unsigned long currentTime;
int BPM = 0;

unsigned long initialTime;
int interval = 10000; // to okbserve heartbeat peaks for 10 seconds
// int num_of_beats = 0;
int pulse_counts = 0;

int reading = 0;



// int Bpm = 0;

int led = 13;


// #define Highpulse 540

// float pulseIntervals[NUM_SAMPLES];  // Store pulse intervals



// -------------------------------
// const int analogPin = 34;

void scan_display_address() {
    Serial.begin(115200);
    Wire.begin();
    
    // Start the I2C communication
    Serial.println("I2C Scanner");

    // Scan all I2C addresses from 1 to 127
    for (byte address = 1; address < 127; address++) {
      Wire.beginTransmission(address);
      byte error = Wire.endTransmission();
      
      // Print out errors or success
      if (error == 0) {
        Serial.print("I2C device found at address 0x");
        if (address < 16) {
          Serial.print("0");
        }
        Serial.println(address, HEX);
      } else if (error == 4) {
        Serial.print("Unknown error at address 0x");
        if (address < 16) {
          Serial.print("0");
        }
        Serial.println(address, HEX);
      }
    }
    Serial.println("Scanning complete.");

}

void clearDisplay(){
  display.clearDisplay();
  // displayText("Heart Rate: ", 1, 0,0);
}

void display_init() {
    // about display--------------------
    // Start I2C communication
    // Wire.begin(3, 4); // SDA = GPIO 3, SCL = GPIO 4
    Wire.begin(SDA_PIN, SCL_PIN);

    // Initialize Serial for debugging
    // Serial.begin(115200);
    
    // Initialize the OLED display
    while (!display.begin(SSD1306_SWITCHCAPVCC, OLED_I2C_ADDRESS)) {
      // Serial.println(F("SSD1306 allocation failed"));
      
      digitalWrite(led, HIGH);
      delay(2000);
      digitalWrite(led, LOW);
      delay(2000);
      // for (;;); // Infinite loop if display initialization fails
      }

    // while (display.begin(OLED_I2C_ADDRESS, OLED_RESET)) {

    //   digitalWrite(led, HIGH);
    //   delay(200);
    //   digitalWrite(led, LOW);
    //   delay(200);
    //   this worked and out display turned on

    //   // f
    // }

    // Clear the display buffer
  // display.clearDisplay();
  // display.fillRect(0, 0, SCREEN_WIDTH / 2, SCREEN_HEIGHT / 2, SSD1306_WHITE);  // White rectangle
  // display.fillRect(SCREEN_WIDTH / 2, 50, SCREEN_WIDTH / 2, SCREEN_HEIGHT / 2, SSD1306_BLACK);  // Black rectangle

  //-------------
    display.clearDisplay();

//     // Set text color and size
//     /*
//     [
//     SSD1306_WHITE,
//     SSD1306_BLACK,
//     SSD1306_INVERT
//     ]
//     */
    display.setTextColor(SSD1306_WHITE);
    display.setTextSize(2);

    // Display a message
    display.setCursor(12, 30);
    display.println(F("WELSTECH"));


    display.setTextColor(SSD1306_WHITE);
    display.setTextSize(1);
    // Display a message
    display.setCursor(0, 0);
    display.println(F("welcome"));



    // ----------
    // Update the display content / Display everything on the screen
    display.display();


    
}

void displayText(String text, int textSize, int posX = 0, int posY = 0) {
  // clearDisplay();
  // Set the text size and color
  display.setCursor(posX, posY);
  display.setTextSize(textSize);          // Text size (1-10)
  display.setTextColor(SSD1306_WHITE);   

  // Print the text to the display
  display.println(text);
  
  // Update the display to show the text
  display.display();
  
}




void setup() {
    Serial.begin(115200);

    Wire.setClock(400000);  // Set I2C clock speed to 100kHz (default is 400kHz)

    // for (int i = 0; i < NUM_SAMPLES; i++) {
    //   pulseIntervals[i] = 0;
    // }

    pinMode(led, OUTPUT);

    pinMode(SENSOR_SIGNAL_PIN_ADC, INPUT);
    // Set the action button pin (for potential use in your project)
    pinMode(ACTION_BUTTON_PIN, INPUT_PULLUP);
    
    // Attach interrupt to detect pulse on rising edge
    // attachInterrupt(digitalPinToInterrupt(SENSOR_SIGNAL_PIN_ADC), pulseISR, RISING);

    // Initial time
    // lastPulseTime = millis();  // Assuming the button is active low

    display_init();
    delay(2000); //to show welstech for some time, show logo and stuff
    
    clearDisplay();

}

int calcBPM(int counts, int interval) {
  // int result = (counts/interval) * 60 ;
  int result = (counts*60)/(interval/1000);
  counts = 0;
  return result;
}

void loop() {
    // Read the analog value from the heart rate sensor
    float currentReading = analogRead(SENSOR_SIGNAL_PIN_ADC);

    /*
    after some observations:
    currentReading seems to reach 1980-2000+ when pulse detected
    and below that when np pulse detected
    */

    // getPulse();
    delay(400);
    clearDisplay();
    char buffer[10];
    dtostrf(currentReading, 4, 2, buffer);
    String newtext = "Ang val:\n" + String(buffer);
    displayText(newtext, 2, 0,30);
    // displayText(String(millis()), 2, 0,30);
    currentTime = millis();  // Get current time
    


    // Detect peak when value rises above the threshold
    // if (currentReading > threshold && !peakDetected) {
    //     peakDetected = true;

    //     //WHAT IF WE DELAY A FEW SECONDS BEFORE 
    //     // WE START READING, AFTER THE FIRST DETECTION 
    //     reading = 1;
    //     clearDisplay();
        
    //     pulse_counts++;

    //     displayText("Peak", 2, 12,30);
    //     displayText(String(pulse_counts), 1, 110,56);
        

    //     if (currentTime - initialTime >= interval) { // SOMETHING IS OFF HERE // (currentTime - initialTime >= interval)
          
    //       initialTime = currentTime;

    //       String newRes = String(calcBPM(pulse_counts, interval));

    //       pulse_counts = 0;

    //       clearDisplay();
    //       displayText(newRes, 2, 55,30);
    //       displayText("BPM", 1, 60, 46);

    //       // pulse_c
    //       reading = 0;
          
    //       // pulse_counts = 0; //
    //       delay(interval/2); // CONTROL THIS LATER
    //       // delay(2500); //
    //       clearDisplay();
    //     }
    
    //     // }
    //     // lastPeakTime = currentTime;  // Update last peak time
    //     delay(25);
    // }
    // else {
      
    //   if (reading == 0){
    //     // clearDisplay();
    //     displayText("--", 2, 50,30);
    //     displayText("READING", 1, 40, 46);

    //   }
      
    // }

    // // Reset peak detection when signal drops
    // //ADJUST THIS AND THRESHOLD, UNLTIL WE GET AN ACCEPTABLE VALUE
    // if (currentReading < threshold - 80) { // was 100 before, adjust accordinlgy. Small buffer to avoid double counting
    //     peakDetected = false;
    // }
    

    // // if (digitalRead(ACTION_BUTTON_PIN) == LOW) { //eliminated button
    // //   while (digitalRead(ACTION_BUTTON_PIN) == LOW) {}
    // // }

    // // getPulse3();

    // // delay(25);
    
    // // delay(200);






}

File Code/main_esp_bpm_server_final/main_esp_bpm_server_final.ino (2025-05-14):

#include <WiFi.h>

// Red Green adn Blue pins
#define red 2
// #define green 4
#define blue 4 // change to 8

bool rState = false;
// bool gState = false;
bool bState = false;

String resultString = "--";

#define SENSOR_SIGNAL_PIN_ADC 7  // GPIO1 for the heart rate sensor signal

//----------
#define MIN_BPM 30     // Set a minimum heart rate threshold for valid data
#define MAX_BPM 200 
#define NUM_SAMPLES 5

//last try variables ---------

//-----------
int threshold = 852;//860; //846-848 arasi//840-850 arasi   //1980 Adjust this based on your readings
bool peakDetected = false;
unsigned long lastPeakTime = 0;
unsigned long currentTime;
int BPM = 0;

unsigned long initialTime;
int interval = 10000; // to okbserve heartbeat peaks for 10 seconds
// int num_of_beats = 0;
int pulse_counts = 0;

int reading = 0;

float currentReading = 0;
//access point stuff----------

const char *ssid = "ESP32-Access-Point";
const char *password = "12345678";  // Optional, minimum 8 chars

WiFiServer server(80);
WiFiClient client;  // listen for incoming clients
bool connected = false;

void setup() {
    Serial.begin(115200);
      

    pinMode(red, OUTPUT);
    // pinMode(green, OUTPUT);
    pinMode(blue, OUTPUT);

    pinMode(SENSOR_SIGNAL_PIN_ADC, INPUT);


    WiFi.softAP(ssid, password);

    IPAddress IP = WiFi.softAPIP();
    Serial.print("Access Point IP address: ");
    Serial.println(IP);  // Should be 192.168.4.1

    server.begin();
    
}

int calcBPM(int counts, int interval) {
  // int result = (counts/interval) * 60 ;
  int result = (counts*60)/(interval/100);
  counts = 0;
  return result;
}

void post(String message){
  
  if (client && connected == true) {
    client.println("HTTP/1.1 200 OK");
    client.println("Content-Type: text/plain");
    client.println("Connection: close");
    client.println();
    client.println(message);
  }
}



void detect_Peaks() {
  // Update pulse count if peak detected
  // if (currentReading > threshold && !peakDetected && currentReading < (threshold)) { //threshold+2 = 848 for now
  if (currentReading > threshold) { //threshold+2 = 848 for now

    peakDetected = true;
    // reading = 0;
    pulse_counts++;
  }

  // // Reset peak detection if signal drops
  // if (currentReading < threshold - 80) {
  //   peakDetected = false;
  // }

  // Time to calculate BPM?
  if (currentTime - initialTime >= interval) {
    initialTime = currentTime;
    if (pulse_counts > 0) {
      String newRes = String(calcBPM(pulse_counts, interval));
      // post(newRes);
      resultString = newRes;

      // reading = 1;
    } else {
      post("No P. D.");
      // resultString = "No P. D.";
    }
    pulse_counts = 0;
  } else if (reading == 0) {
    // post("Reading");
    // resultString = "Reading";
  }

  // pulse_counts = 0;

  delay(20);  // Control sample rate
}


String get_rawDemo(float value) {
  // delay(400);//remove delay if necessary
  // clearDisplay();
  int tempint = (int)value;
  char buffer[10];
  dtostrf(tempint, 4, 2, buffer);
  String newtext = "" + String(buffer);
  
  // displayText(newtext, 2, 0,30); //post to http server
  // displayText(String(millis()), 2, 0,30);
  return newtext;
}


void loop() {
    // Read the analog value from the heart rate sensor
    currentReading = analogRead(SENSOR_SIGNAL_PIN_ADC);

    /*
    after some observations:
    currentReading seems to reach 1980-2000+ when pulse detected
    and below that when np pulse detected
    */

    
    currentTime = millis();  // Get current time
    // unsigned long ledCurrentMillis = millis();

    detect_Peaks(); 


    client = server.available();  // listen for incoming clients

    //-------------------------------------------
    if (client) {
      // connected = true;
      
      // Serial.println("New Client Connected");
      
      // while (client.connected()) {

      connected = true;
      Serial.println("New Client Connected");

      String request = client.readStringUntil('\r');
      Serial.println("Request: " + request);
      client.flush();


      //detect_Peaks(); //uncoment this, after getting the optimum threshold
      // post(get_rawDemo(currentReading));//after getting the optimum threshold, comment this out
      post(resultString);

      // if (resultString == "Reading"){

      // }
      // else{
      //   delay(interval/2);
      // }

      // if (reading == 1){
      //   delay(interval/2);
      //   reading = 0;
      // }

      client.stop();  // disconnect after sending response
      Serial.println("Client Disconnected");
            
      
    }
    else{
      
      connected = false;
    }

    delay(30);
    

}
